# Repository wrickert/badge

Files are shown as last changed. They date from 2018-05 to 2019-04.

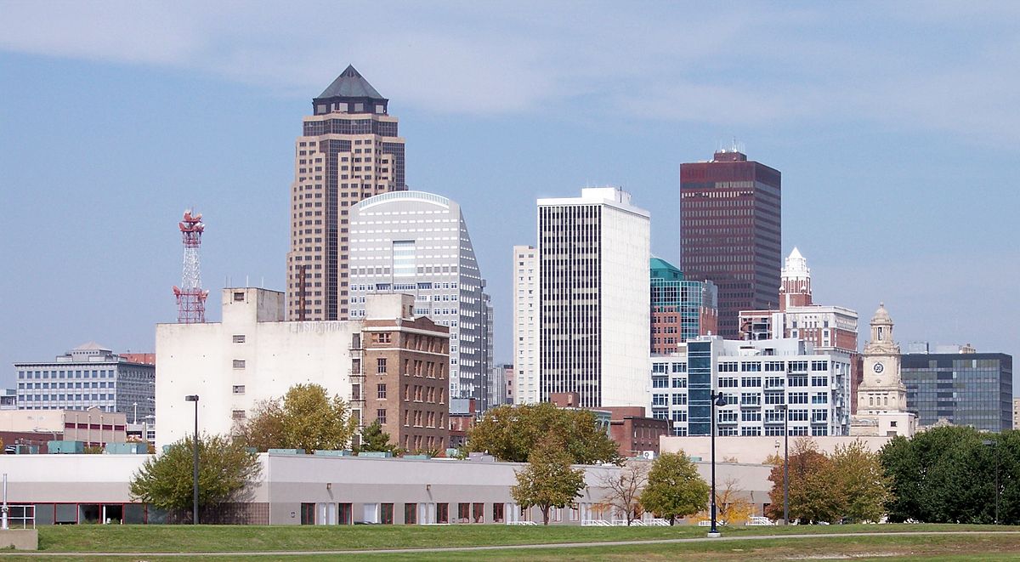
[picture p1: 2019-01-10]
Documents/1200px-Des_Moines_skyline.jpg

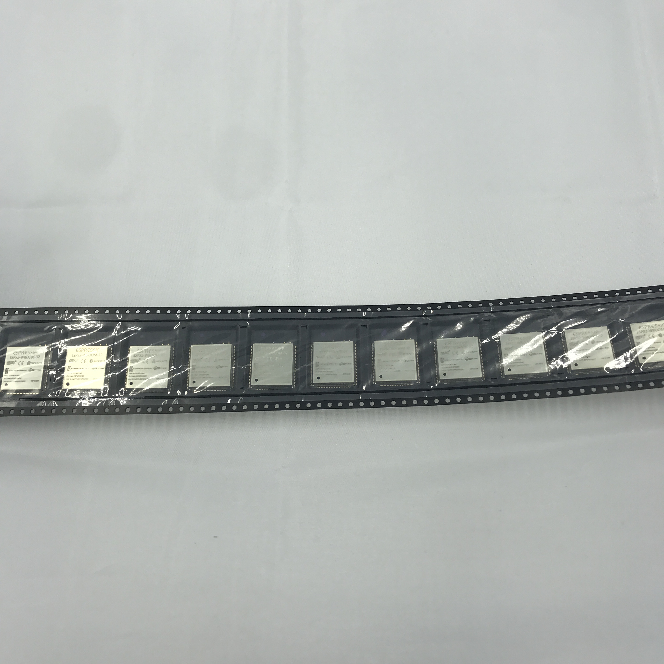
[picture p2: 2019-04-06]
Documents/ESP32-WROOM-32+ESP-32+%286%29.jpg

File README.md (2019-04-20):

<h2> BSidesIowa 2019 Badge </h2>
The badge for BSidesIowa 2019 conference is a penny piano running on an ESP32 microcontroller running micropython.
This badge is fully rechargeable and all that is required to program it is a micro usb cable. 

<h3> Micropython </h3>
The micropython REPL prompt can be accessed using a serial console running at 115200 baud. 
Documentation for micropython can be found here, https://docs.micropython.org/en/latest/esp32/quickref.html

<h3> To program </h3>
The badge can be programmed directly through the REPL prompt on the serial console. To load new files onto the ESP32, first access the serial console and press Ctrl+C to end the running program on the board. Then, exit the serial console and use ampy.py to load new programs. Instructions to install ampy can be found here, https://learn.adafruit.com/micropython-basics-load-files-and-run-code/install-ampy

Common ampy commands:<br>
To program the board: ampy -p /dev/ttyUSB0 put main.py

<h3> Troubleshooting </h3>
If you encounter problems programming the badge using ampy it may be because the badge is in sleep mode. Press any penny to wake the badge up and then you should be able to program.<br>
Note: sleep mode has a polling interval of 1 second, there may be a delay of up to 1 second before badge responds.<br>

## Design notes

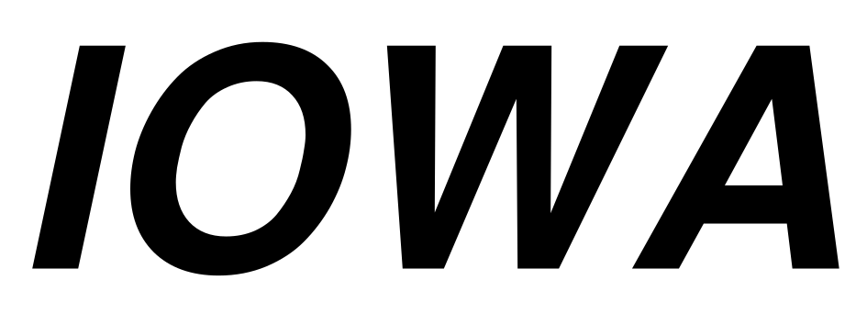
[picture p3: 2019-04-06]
Footprints/.svg2shenzhen-cache/images/F.Cu_g1425.png

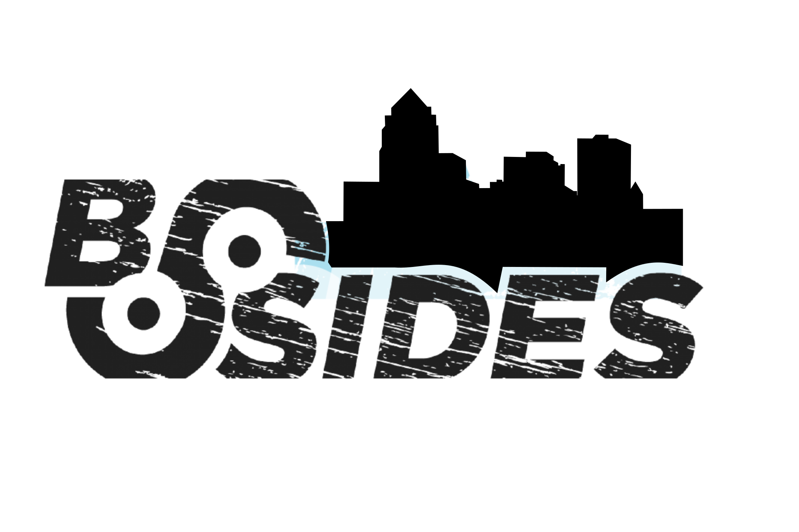
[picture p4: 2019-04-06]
Footprints/.svg2shenzhen-cache/images/F.Cu_g832.png

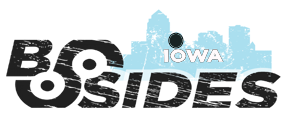
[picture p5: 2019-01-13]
Documents/DSM BSIDESminusIowa.png

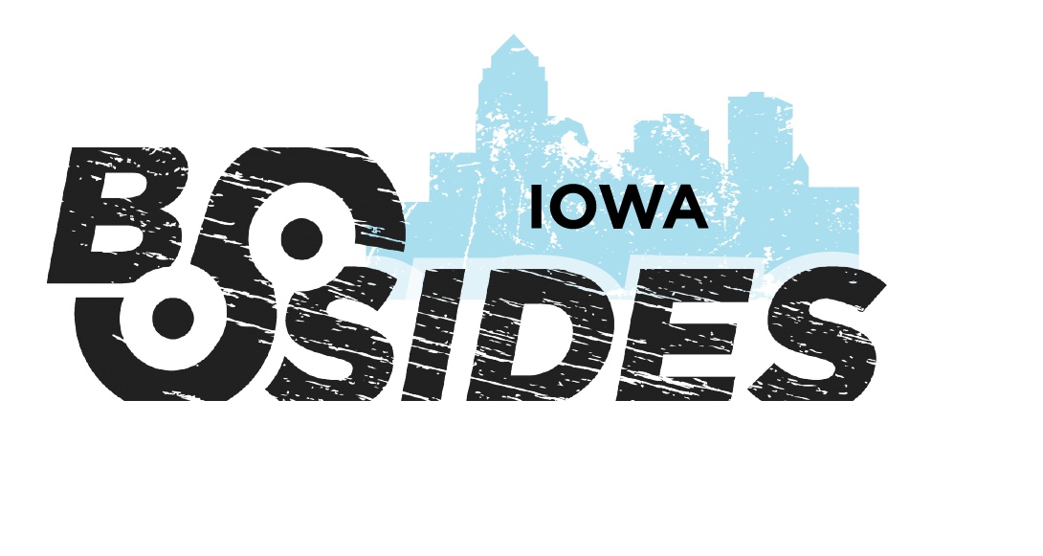
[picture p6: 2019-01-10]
Documents/DSM BSIDES.png

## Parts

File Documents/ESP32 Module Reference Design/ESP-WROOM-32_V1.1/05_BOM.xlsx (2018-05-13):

Item | Quantity | Reference | Specifications
1 | 2 | C1,C2 | 22pF±5%/50V, 0402
2 | 1 | C3 | 100pF±5%/50V, 0402
3 | 4 | C4,C9,C10,C19 | 0.1uF±10%/10V, 0402
4 | 1 | C5 | 10nF±10%/6.3V, 0402
5 | 1 | C6 | 3.3nF±10%/50V, 0402
6 | 3 | C11,C18,C20 | 1uF ±10%/16V,0402
7 | 0 | C12 | NC
8 | 1 | C13 | 10uF±20%/6.3V,0603
9 | 1 | C14 | GRM1555C1H4R7BA01D (4.7pF +/-0.1pF,0402)
10 | 1 | C15 | GRM1555C1H2R4CA01D (2.4pF +/-0.25pF,0402)
11 | 2 | C16,C17 | 270pF±5%/50V, 0402
12 | 1 | L4 | LQP15MN2N4B02D(2.4nH±0.1nH,0402)
13 | 1 | D1 | ESD3.3V88D-LCDN,DFN1006
14 | 1 | R1 | 20K±1%/16W,0402
15 | 1 | U1 | 40M Crystal, +/-10ppm,3225
16 | 1 | U2 | ESP32,QFN48_6X6
17 | 1 | U3 | Flash,SOP8-208mil,GD25Q32
* Please be noted that C14, C15 and L4 are recommended to use Murata for good quality and accuracy.

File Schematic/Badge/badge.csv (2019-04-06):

Id | Designator | Package | Quantity | Designation | OLD Price per part | New Price Per Part | Total per board | New Total per board | Shipping | Link and Ref
1 | U2 | SOIC-8_3.9x4.9mm_Pitch1.27mm | 1 | otter_CH330 | 0.3163 | 0.3162 | 0.3163 | 0.3162 |  | https://lcsc.com/product-detail/USB_CH330N_C108996.html
2 | 0101,0001,0100,1000,1100,0010,1010,0110,1110,1001 | WS2812B-Sunken | 10 | WS2812B | 0.045 | 0.039 | 0.45 | 0.39 | 33 | alibaba
3 | U1 | ESP32-WROOM | 1 | ESP32-WROOM | 3.7 | 2.6 | 3.7 | 2.6 | 28 | alibaba
4 | BT1 | Keystone_3009_1x2450-CoinCell | 1 | Battery_Cell | 0.45 | 0.48 | 0.45 | 0.48 | 45 | alibaba
 | Battery Holder |  | 1 |  | 0 | 0.1 | 0 | 0.1 | 30
5 | C1,C2,C3,C4,C5,C6,C7,C8,C9,C10,C11,C12,C15,C19 | C_0805_HandSoldering | 14 | 0.1uF | 0.00828 | 0.0065 | 0.11592 | 0.091 |  | https://www.digikey.com/product-detail/en/samsung-electro-mechanics/CL21F104ZBCNNNC/1276-1007-2-ND/3886665
6 | C13 | C_0805_HandSoldering | 3 | 10uF | 0.0259 | 0.0131 | 0.0259 | 0.0393 |  | https://www.digikey.com/product-detail/en/samsung-electro-mechanics/CL21A106KQCLRNC/1276-2405-1-ND/3890491
7 | R1 | R_0805_HandSoldering | 1 | 10k | 0.0075 | 0.0018 | 0.0075 | 0.0018 |  | https://www.digikey.com/product-detail/en/bourns-inc/CR0805-JW-103ELF/CR0805-JW-103ELFCT-ND/3592918
16 | LS1 | XDCR_PKMCS0909E4000-R1 | 1 | PKMCS0909E4000-R1 | 0.90448 | 0.22 | 0.90448 | 0.22 | 25 | https://www.digikey.com/product-detail/en/murata-electronics-north-america/PKMCS0909E4000-R1/490-9647-1-ND/4878401
19 | C16,C18 | C_0805_HandSoldering | 2 | 1uF | 0.0266 | 0.011 | 0.0532 | 0.022 |  | https://www.digikey.com/product-detail/en/samsung-electro-mechanics/CL21B105KAFNFNE/1276-2926-1-ND/3891012
21 | R2 | R_0805_HandSoldering | 1 | 1k | 0.0085 | 0.0018 | 0.0085 | 0.0018 |  | https://www.digikey.com/product-detail/en/stackpole-electronics-inc/RMCF0805JT2K00/RMCF0805JT2K00CT-ND/1942562
22 | U4 | SOT-223-3_TabPin2 | 1 | TLV1117-33 | 0.43 | 0.11 | 0.43 | 0.11 |  | https://www.digikey.com/product-detail/en/texas-instruments/TLV1117-33CDCYR/296-21112-1-ND/1217055
23 | J10 | USB_Micro-B_Molex_47346-0001 | 1 | USB_B_Micro | 0.5629 | 0.04 | 0.5629 | 0.04 |  | https://lcsc.com/product-detail/USB-Connectors_MOLEX_47346-0001_47346-0001_C132560.html
24 | R3 | R_0805_HandSoldering | 1 | 0ohm | 0 | 0 | 0 | 0
25 | U3 | SOT-23-5_HandSoldering | 1 | MCP73831-2-OT | 0.4326 | 0.045 | 0.4326 | 0.045 |  | https://www.digikey.com/product-detail/en/microchip-technology/MCP73831T-2ACI-OT/MCP73831T-2ACI-OTCT-ND/1979802
26 | R4 | R_0805_HandSoldering | 1 | 22ohm | 0.0085 | 0.0085 | 0.0085 | 0.0085 |  | https://www.digikey.com/product-detail/en/stackpole-electronics-inc/RMCF0805JT22R0/RMCF0805JT22R0CT-ND/1942533
 |  |  | 1 | Circuit board from jlcpcb | 0.66 | 0.66 | 0.66 | 0.66
 |  |  |  |  | Total per board: |  | 8.23116 | 5.1256
 |  |  |  |  | Total Order: |  | 2057.79 | 1281.4 | 161
 |  |  |  |  |  |  |  | Total shipping per board: | 0.644
 |  |  |  |  |  |  | Grand Total: | 1442.4

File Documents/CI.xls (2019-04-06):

Commercial Invoice
Consigner (Name＆Address) | Consignee(Name＆Address)
Company: Shenzhen Yuzens Technologies Co. Ltd | Company:
Consigner: Ela HONG | Consignee: William Rickert
Address： Duhui Building, Zhonghang Road Futian Dist. Shenzhen,GuangDong | Address: 2326 Edenburn Dr,Apt 38A,Ames,Iowa
TEL:+86 13728628651 | TEL: +1-3035235910
Postal Code: 518031 | Zip code: 50010
Country of Origin:China | Country of destination: United States of America
Description of Goods | Qty(PCS) | Unit Value | Total Value(USD)
sensor module | 250 | 2.7 | 675
Total Amount |  |  | US$675.00

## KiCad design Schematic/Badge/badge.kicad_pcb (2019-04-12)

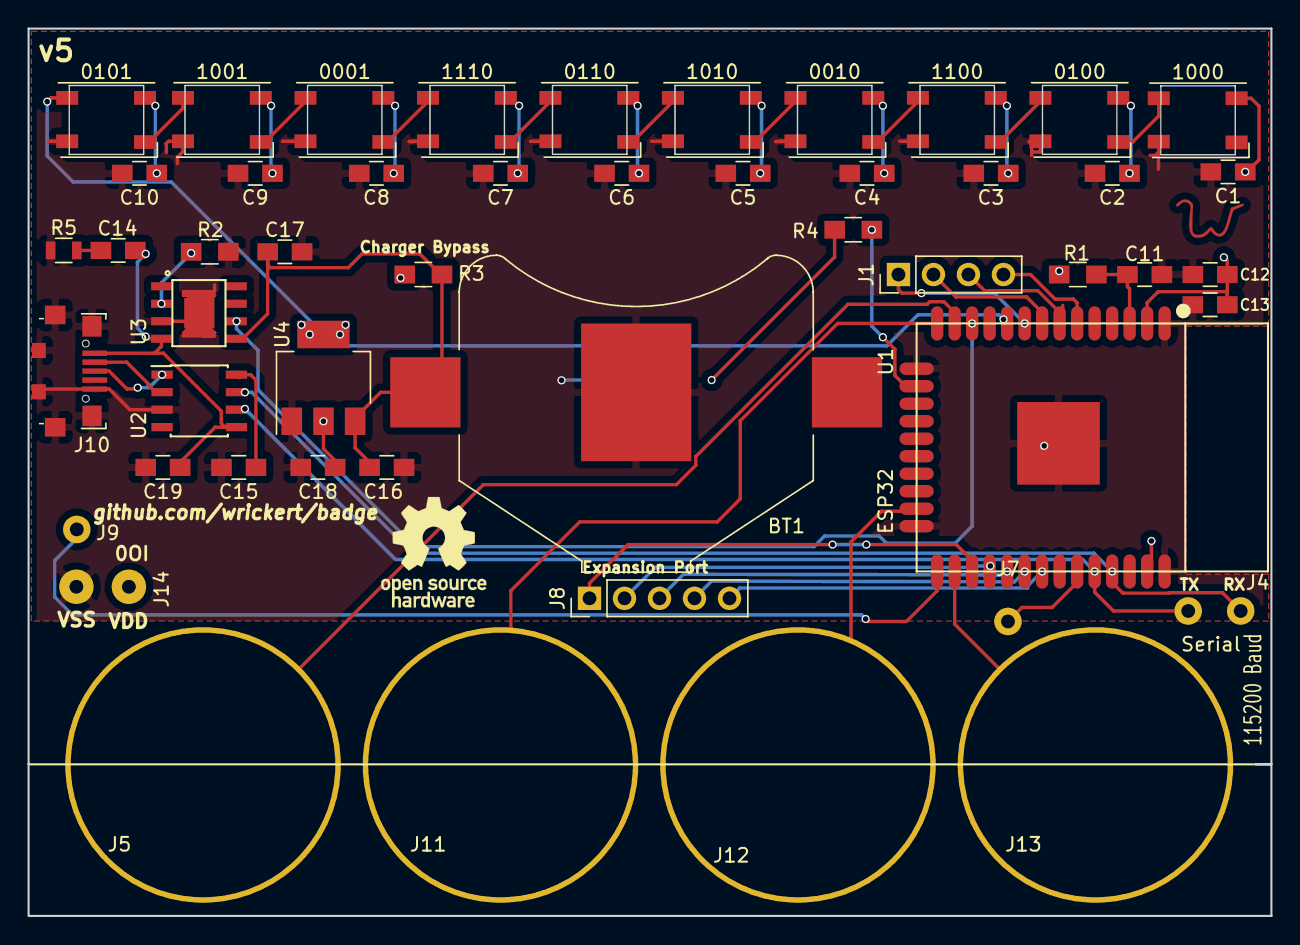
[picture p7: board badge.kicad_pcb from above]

Board: 2 copper layers, 90.2 x 64.4 mm, 52 parts (1 on the bottom side), 40 nets.

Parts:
0001, 0010, 0100, 0101, 0110, 1000, 1001, 1010, 1100, 1110: WS2812B; WS2812B-Sunken
BT1: Battery_Cell; Keystone_3008_1x2450-CoinCell
C1, C2, C3, C4, C5, C6, C7, C8, C9, C10, C11, C12, C15, C19: 0.1uF; C_0805_HandSoldering
C13, C14, C17: 10uF; C_0805_HandSoldering
C16, C18: 1uF; C_0805_HandSoldering
J1: Left2; Pin_Header_Straight_1x04_Pitch2.54mm
J4: Serial; SolderWirePad_2x_1mmDrill
J5: Penny3; Penny
J7: Right2; SolderWirePad_single_1mmDrill
J8: Right3; Pin_Header_Straight_1x05_Pitch2.54mm
J9: Right4; SolderWirePad_single_1mmDrill
J10: USB_B_Micro; USB_Micro-B_Jing
J11: Penny2; Penny
J12: Penny1; Penny
J13: Penny0; Penny
J14: Power; SolderWirePad_2x_1mmDrill
LS1: PKMCS0909E4000-R1; XDCR_PKMCS0909E4000-R1
R1: 10k; R_0805_HandSoldering
R2: 1k; R_0805_HandSoldering
R3: 0ohm; R_0805_HandSoldering
R4: 22ohm; R_0805_HandSoldering
R5: 1.5; R_0805
Ref**: Val**; W
U1: ESP32-WROOM
U2: otter_CH330; SOIC-8_3.9x4.9mm_Pitch1.27mm
U3: HX4056
U4: TLV1117-33; SOT-223-3_TabPin2

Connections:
IO0: J9.1, U1.25
IO5: J8.3, U1.29
IO13: R4.1, U1.16
IO16: J8.1, U1.27
IO17: J8.2, U1.28
IO18: J8.4, U1.30
IO19: J8.5, U1.31
IO21: J7.1, U1.33
IO27: U1.12, U3.6
IO32: J1.2, U1.8
IO33: J1.1, U1.9
IO34: J1.4, U1.6
IO35: J1.3, U1.7
unnamed: C11.1, R1.2, U1.3
unnamed: C14.1, R5.2
unnamed: C15.1, U2.8
unnamed: J10.2, U2.2
unnamed: J10.3, U2.1
unnamed: 0100.4, 1000.2
unnamed: 0100.2, 1100.4
unnamed: 0010.4, 1100.2
unnamed: 0010.2, 1010.4
unnamed: 0110.4, 1010.2
unnamed: 0110.2, 1110.4
unnamed: 0001.4, 1110.2
unnamed: 0001.2, 1001.4
unnamed: 0101.4, 1001.2
unnamed: LS1.1, R4.2
unnamed: R2.1, U3.2
P0: J13.1, U1.26
P1: J12.1, U1.23
P2: J11.1, U1.14
P3: J5.1, U1.13
RX: J4.1, U1.35, U2.7
SPI: 0101.2, U1.10
TX: J4.1, U1.34, U2.6
VBUS: C14.2, C19.2, J10.1, U2.5, U3.4
VDD: 0001.1, 0010.1, 0100.1, 0101.1, 0110.1, 1000.1, 1001.1, 1010.1, 1100.1, 1110.1, C1.1, C2.1, C3.1, C4.1, C5.1, C6.1, C7.1, C8.1, C9.1, C10.1, C12.2, C13.2, C18.1, J14.1, R1.1, R3.1, U1.2, U4.2
VDDA: BT1.1, C16.1, C17.2, R3.2, U3.5, U4.3
VSS: 0001.3, 0010.3, 0100.3, 0101.3, 0110.3, 1000.3, 1001.3, 1010.3, 1100.3, 1110.3, BT1.2, C1.2, C2.2, C3.2, C4.2, C5.2, C6.2, C7.2, C8.2, C9.2, C10.2, C11.2, C12.1, C13.1, C15.2, C16.2, C17.1, C18.2, C19.1, J10.5, J10.6, J14.1, LS1.2, R2.2, R5.1, U1.1, U1.15, U1.24, U1.38, U1.39, U2.3, U3.3, U3.9, U4.1

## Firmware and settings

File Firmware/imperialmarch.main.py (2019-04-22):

#rename to main.py to use with the exsisting code
import rainbowPiano
import time
from notes import *
from math import ceil
import machine

machine.freq(80000000)

def play_march():
    """
    Play the Imperial March.
    :return:
    """
		rainbowPiano.play_note(A4, .500)
		rainbowPiano.play_note(A4, .500)
		rainbowPiano.play_note(A4, .500)
		rainbowPiano.play_note(F4, .350)
		rainbowPiano.play_note(C5, .150)
		rainbowPiano.play_note(A4, .500)
		rainbowPiano.play_note(F4, .350)
		rainbowPiano.play_note(C5, .150)
		rainbowPiano.play_note(A4, .650)

		time.sleep(.500)

		rainbowPiano.play_note(E5, .500)
		rainbowPiano.play_note(E5, .500)
		rainbowPiano.play_note(E5, .500)
		rainbowPiano.play_note(F5, .350)
		rainbowPiano.play_note(C5, .150)
		rainbowPiano.play_note(GS4, .500)
		rainbowPiano.play_note(F4, .350)
		rainbowPiano.play_note(C5, .150)
		rainbowPiano.play_note(A4, .650)

		time.sleep(.500)

    #rainbowPiano.clear()

# POST stuff for testing
f = open('silent.txt')
if f.read() == 'f':
    play_march()

    rainbowPiano.inital()

else:
    f.close()
    f = open('silent.txt', 'w')
    f.write('f')

f.close()
machine.freq(40000000)
rainbowPiano.keys()

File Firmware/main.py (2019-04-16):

import rainbowPiano
import time
from notes import *
from math import ceil
import machine

machine.freq(80000000)


def play_zelda():
    """
    Play the main theme from Link's awakening.
    :return:
    """
    rainbowPiano.play_note(AS5, .314)
    time.sleep(.091)
    rainbowPiano.play_note(F5, .522)
    rainbowPiano.play_note(AS5)
    rainbowPiano.play_note(AS5)
    rainbowPiano.play_note(C6)
    rainbowPiano.play_note(D6)
    rainbowPiano.play_note(DS6)
    # 1.19
    rainbowPiano.play_note(F6, .506)
    time.sleep(.507)
    rainbowPiano.play_note(F6)
    time.sleep(.1)
    rainbowPiano.play_note(F6)
    time.sleep(.1)
    rainbowPiano.play_note(FS6)
    rainbowPiano.play_note(GS6)
    # 3.07
    rainbowPiano.play_note(AS6, .517)
    # Top of the first swell

    rainbowPiano.play_note(AS6)
    time.sleep(.1)
    rainbowPiano.play_note(AS6)
    time.sleep(.1)
    rainbowPiano.play_note(GS6)
    rainbowPiano.play_note(FS6)
    # 4.26
    rainbowPiano.play_note(GS6, .304)
    rainbowPiano.play_note(FS6)
    rainbowPiano.play_note(F6, .507)
    time.sleep(.241)
    rainbowPiano.play_note(F6, .304)
    time.sleep(.1)
    # 6.15
    rainbowPiano.play_note(DS6, .315)
    rainbowPiano.play_note(F6)
    rainbowPiano.play_note(FS6, .517)
    time.sleep(.304)
    rainbowPiano.play_note(F6)
    time.sleep(.1)
    rainbowPiano.play_note(DS6)
    time.sleep(.1)
    # 8.03
    rainbowPiano.play_note(CS6)
    rainbowPiano.play_note(DS6)
    rainbowPiano.play_note(F6, .506)
    time.sleep(.304)
    rainbowPiano.play_note(DS6)
    time.sleep(.1)
    rainbowPiano.play_note(CS6)
    time.sleep(.1)
    # 9.22
    rainbowPiano.play_note(C6, .304)
    rainbowPiano.play_note(D6)
    rainbowPiano.play_note(E6, .497)
    time.sleep(.304)
    rainbowPiano.play_note(G6, .314)
    time.sleep(.1)
    # 11.11
    rainbowPiano.play_note(F6)
    time.sleep(.1)
    rainbowPiano.play_note(ceil((AS5 + F5) / 2))
    time.sleep(.001)
    rainbowPiano.play_note(ceil((AS5 + F5) / 2))
    time.sleep(.001)
    rainbowPiano.play_note(ceil((AS5 + F5) / 2))
    time.sleep(.1)
    rainbowPiano.play_note(ceil((AS5 + F5) / 2))
    time.sleep(.001)
    rainbowPiano.play_note(ceil((AS5 + F5) / 2))
    time.sleep(.001)
    rainbowPiano.play_note(ceil((AS5 + F5) / 2))

    #rainbowPiano.clear()



# POST stuff for testing
f = open('silent.txt')
if f.read() == 'f':
    play_zelda()

    rainbowPiano.inital()

else:
    f.close()
    f = open('silent.txt', 'w')
    f.write('f')

f.close()
machine.freq(40000000)
rainbowPiano.keys()

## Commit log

2018-05-13 Added schematic
    [05_BOM.xlsx, SCH_ESP_WROOM_32_6X6.DSN, badge.kicad_pcb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]
2018-05-14 Finished v1 schematic
    [_saved_badge.sch]
2018-05-14 Changed pin for speaker and added schematic symbol
2018-05-14 Checking for update
    [_saved_badge.sch, badge.sch]
2018-06-05 New board revision
    [_saved_badge.sch, badge.kicad_pcb]
2018-06-05 New board revision - power pins again
    [badge.kicad_pcb]
2018-06-12 Fixed pizeo and power screen printing
    [badge.kicad_pcb]
2019-01-04 vallen says hi
    [_saved_badge.sch, badge.kicad_pcb, badge.sch]
2019-01-10 Added charging hardware
    [Bsides.kicad_pcb, _saved_badge.sch, badge-2019-01-04-19-17-11.sch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]
2019-01-13 Ordered V3
    [DSM BSIDES.kicad_pcb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]
2019-01-13 Added bom
    [badge.csv]
2019-01-19 Ordered v3 from pcbway
    [badge-B.Cu.gbr, badge-B.Mask.gbr, badge-B.SilkS.gbr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]
2019-01-19 Created bom
    [badge.csv]
2019-01-31 Fixed issues with v3, rearranged caps to make assembly eaiser
    [_saved_badge.sch, badge-2019-01-04-19-17-11.sch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]
2019-02-20 v4, changes to add all of the best chineseium bits I can find
    [_saved_badge.sch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]
2019-04-06 v5 arrived
    [CI.xls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]
2019-04-12 Oh we oh, oh-we-oh
    [badge.kicad_pcb]
2019-04-12 Added the Pokemon Red/Blue theme
    I'm not happy with how it sounds. This song is a bit too low and
    brooding for this hardware, and the timing is a bitch.
    May want to look into other songe. Something a bit happier.
    Also need to add lights.
    [main.py, notes.py, rainbowPiano.py]
2019-04-13 Added silent reboot for value error
    [main.py, rainbowPiano.py]
2019-04-15 Added dimming display to improve battery life
2019-04-16 Improved battery life
2019-04-17 bug fix
    [59233635.csv]
